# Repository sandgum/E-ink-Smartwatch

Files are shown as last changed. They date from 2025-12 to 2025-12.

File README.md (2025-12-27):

# Triangulate ES_01 E-ink Watch
---
An ultra-thin ESP32S3-based smartwatch (at just 5mm thick at its thickest point) which uses an E-ink display and two OLEDs to display information while consuming a small amount of power. The main E-ink panel is touch-enabled, with the two additional OLED panels above and below it displaying auxiliary information, such as notifications, background activities etc. 
The watch has built-in heart rate and spO2 sensing via an Analog Devices MAX30102, high-precision smart movement sensing via a Bosch BH260AP IMU and a Bosch BMP585 barometric pressure sensor.

render1
render10

*ACKNOWLEDGMENT: Most of the materials and the human hand model you see in the renders are not my own work, but is Royalty-free or CC0 licensed work legitimately downloaded from BlenderKit using their free plan*

---

To top it all off, the ES_01 is completely workout-friendly, with rubberised sides and no pesky side buttons that get pressed mid-pushup (Every physical input is at the top of the watch)!
The watch features a sleek design, with each component being laid out single file and in its own separate segment of the watch. These segments can all bend around the watch, preserving a uniform thickness all around, which also adds the benefit of being aesthetically pleasing.
The main microcontroller running the watch is an Espressif ESP32-S3 running with Bluetooth LE capabilities, which also allow for it to sync with a smartphone to relay notifications, workout, and weather data etc. through firmware based on ESP-IDF and host smartphone software for iPhone based on Swift (Coming soon, and Android support will come later!)

---
## PCB:

-  4 layers
-  Flex PCB
-  Single-sided component placement
-  0.2mm board thickness
-  Added 0.1mm FR4 stiffeners
-  All resistors and capacitors are 0402 size

*Schematics:*
E-ink watch sensors schematic
E-ink watch main schematic
E-ink watch drivers schematic
E-ink watch displays schematic

*PCB Layout and render:*
Screenshot 2025-12-14 at 1 22 46 pm
render4

---

## Enclosure:

- Main cases and top plates of easch segment 3D printed using an SLA/MSLA printer
- Main cases printed in Black resin from JLC3DP (can substitute with any rigid resin)
- Top plates printed in LEDO 6060 resin from JLC3DP (can substitute with any rigid resin)
- Bottom plates for OLED segments are CNC machined from 6061 Aluminium by JLCCNC (can substitute with any rigid material or also with SLA/MSLA printed resin)
- Bottom plate for main E-ink segment 3D printed using an SLM printer in 316L stainless steel (can substitute with other rigid metal with high thermal conductivity)

---

## Assembly instructions:

1. Use the solder stencil to squeegee solder paste onto main PCB
2. Place each component onto its respective pads on the main PCB
3. Use a hotplate or a reflow oven to reflow the solder paste underneath the components
4. Hand-solder a thin insulated wire (enamel insulated or rubber insulated) connecting the pads "BATT1_WIRE" together on the PCB
5. Create a solder bridge connecting the pads "GND_TO_GNDIO" and "GNDIO_TO_GND"
6. Create a solder bridge connecting the pads "GND_TO_GNDPWR" and "GNDPWR_TO_GND"
7. Assemble the two "end battery" segments by threading battery wires through them, placing the battery in and attaching the top plates to their respective main cases with superglue
8. Assemble the other battery segment and the haptic module segment in the same way, but thread the "end battery" wires through the dedicated channels in these segments, you should have two sets of two segments with four wires coming out of each set of segments
9. Take the main cases of the OLED modules and superglue the OLED displays into the top of each, making sure the flex cables poke through their dedicated holes
10. Do the same with the E-ink segment and the E-ink display
11. Attach each remaining top plate to its respective main case using superglue
12. Place and superglue the main Flex PCB into the bottom of the E-ink segment and the two OLED segments. The back of the PCB should face the displays
13. Thread the wires from the two sets of segments from step 8 through the holes in the side of the OLED modules and hand-solder the wires onto their respective pads
14. Plug in the flex cables from each display into thir respective FPC connectors on the main PCB
15. Superglue the bottom panels for the OLED segments onto their respective main cases
16. Apply thermal paste on the ESP32-S3 chip on the main PCB
17. Superglue threaded inserts in the two dedicated holes in the corners of the bottom panel for the E-ink segment
19. Superglue the bottom panel to the main case of the E-ink segment
20. Screw two screws into the holes in the top case of the E-ink segment until they mesh with the threaded inserts from the previous step
21. Take two more screws and cut off their entire threaded sections until just the heads remain. Superglue those heads in the holes in the other two corners of the top panel of the E-ink segment
22. Superglue the side TPU pieces to the sides of all the segments
23. Plug in a patch antenna into the exposed U.FL port on the back of the watch, guide the cable through its designated groove, and stick the patch antenna somewhere on the watch

---
## Bill of materials:

*Electronic Components: (Order quantities account for minimum order quantity of parts from the chosen retailer)*

| Manufacturer Part Number | Mfr. | Order Qty. | Unit Price(USD) | Ext.Price(USD) | Package | Description | Product Link |
|---|---|---|---|---|---|---|---|
| CC0402JRNPO9BN110 | YAGEO | 100 | 0.0012 | 0.12 | 0402 | 11pF ±5% 50V Ceramic Capacitor NP0 0402 | https://www.lcsc.com/product-detail/C527000.html |
| GRM155R61E475ME15D | muRata | 20 | 0.0377 | 0.75 | 0402 | 4.7uF ±20% 25V Ceramic Capacitor X5R 0402 | https://www.lcsc.com/product-detail/C2858031.html  |
| ESP32-S3 | ESPRESSIF | 1 | 2.7791 | 2.78 | QFN-56-EP(7x7) | 150Mbps 2.4GHz 2.412GHz~2.484GHz QFN-56-EP(7x7) RF Transceiver ICs RoHS | https://www.lcsc.com/product-detail/C2913192.html  |
| 2328702-6 | TE Connectivity | 5 | 0.1654 | 0.83 | SMD,P=0.5mm,Surface Mount,Right Angle  | FFC/FPC Connector 6 Position 0.5mm Pitch Double-Sided Contacts, Top and Bottom Entry Surface Mount, Right Angle -40℃~+85℃  | https://www.lcsc.com/product-detail/C3151647.html  |
| FFC2B28-24-G | Global Connector Technology | 1 | 0.5754 | 0.58 | SMD,P=0.5mm,Surface Mount,Right Angle  | FFC/FPC Connector 24 Position 0.5mm Pitch Double-Sided Contacts, Top and Bottom Entry Surface Mount, Right Angle -25℃~+85℃ | https://www.lcsc.com/product-detail/C3151659.html  |
| BHI260AP | Bosch | 1 | 8.7882 | 8.79 | LGA-44 | LGA-44 IMUs (Inertial Measurement Units) RoHS | https://www.lcsc.com/product-detail/C3288651.html  |
| SI1308EDL-T1-GE3 | VISHAY | 5 | 0.1324 | 0.66 | SOT-323 | N-Channel 30V 1.5A 0.4W Surface Mount SOT-323 | https://www.lcsc.com/product-detail/C469327.html |
| XC6206P302MR | HXY MOSFET | 50 | 0.0154 | 0.77 | SOT-23 | Linear Voltage Regulator IC Positive Fixed 1 Output 300mA SOT-23 | https://www.lcsc.com/product-detail/C5148691.html  |
| MBR0530 | Huixin | 20 | 0.0205 | 0.41 | SOD-123 | 5.5A 30V 500mV@500mA 500mA SOD-123 Single Diodes RoHS | https://www.lcsc.com/product-detail/C49435625.html |
| 0402WGF1004TCE | UNI-ROYAL | 100 | 0.0006 | 0.06 | 0402 | 1MΩ ±1% 62.5mW 0402 Thick Film Resistor | https://www.lcsc.com/product-detail/C26083.html |
| CL05A105KA5NQNC | Samsung Electro-Mechanics | 100 | 0.0030 | 0.30 | 0402 | 1uF ±10% 25V Ceramic Capacitor X5R 0402 | https://www.lcsc.com/product-detail/C52923.html |
| XL2EL89CPI-111YLC-40M | YXC Crystal Oscillators | 10 | 0.0578 | 0.58 | SMD3225-4P | Crystal 40MHz ±10ppm 15pF SMD3225-4P | https://www.lcsc.com/product-detail/C5444549.html  |
| TS-1088-AR02016 | XUNPU | 10 | 0.0421 | 0.42 | SMD,4x3mm | Tactile Switch SPST 160gf 2mm SMD (SMT) Tab 4mm x 3mm Surface Mount | https://www.lcsc.com/product-detail/C720477.html |
| BSS138 | R+O | 50 | 0.0170 | 0.85 | SOT-23 | N-Channel 50V 340mA 350mW Surface Mount SOT-23 | https://www.lcsc.com/product-detail/C7420339.html  |
| TCR2EF33,LM(CT | TOSHIBA | 5 | 0.0829 | 0.41 | TSOT-25 | Positive Fixed 3.3V TSOT-25 Voltage Regulators - Linear, Low Drop Out (LDO) Regulators RoHS | https://www.lcsc.com/product-detail/C843273.html |
| LQG15HS3N3S02D | muRata | 100 | 0.0076 | 0.76 | 0402 | 800mA 3.3nH 125mΩ 0402 Fixed Inductors RoHS | https://www.lcsc.com/product-detail/C86064.html |
| MRA4003T3G | onsemi | 10 | 0.0873 | 0.87 | SMA(DO-214AC) | Diode 300V 1A Surface Mount SMA(DO-214AC) | https://www.lcsc.com/product-detail/C94410.html |
| DRV2605LDGSR | TI | 1 | 1.2502 | 1.3 | VSSOP-10-0.5mm | 2V~5.2V I2C VSSOP-10-0.5mm Motor Drivers, Controllers RoHS | https://www.lcsc.com/product-detail/C527464.html |
| LQG15HS2N0S02D | muRata | 100 | 0.0081 | 0.81 | 0402 | 900mA 2nH 90mΩ 0402 Fixed Inductors RoHS | https://www.lcsc.com/product-detail/C18216.html |
| 0402WGF5603TCE | UNI-ROYAL | 100 | 0.0005 | 0.05 | 0402 | 560kΩ ±1% 62.5mW 0402 Thick Film Resistor | https://www.lcsc.com/product-detail/C132339.html |
| CL05B103KB5NNNC | Samsung Electro-Mechanics | 100 | 0.0014 | 0.14 | 0402 | 10nF ±10% 50V Ceramic Capacitor X7R 0402 | https://www.lcsc.com/product-detail/C15195.html |
| 0402B102K500NT | FH | 100 | 0.0011 | 0.11 | 0402 | 1nF ±10% 50V Ceramic Capacitor X7R 0402 | https://www.lcsc.com/product-detail/C1523.html |
| CL05B104KO5NNNC | Samsung Electro-Mechanics | 100 | 0.0012 | 0.12 | 0402 | 100nF ±10% 16V Ceramic Capacitor X7R 0402 | https://www.lcsc.com/product-detail/C1525.html |
| 0402CG1R0C500NT | FH | 100 | 0.0012 | 0.12 | 0402 | 1pF 50V Ceramic Capacitor C0G 0402 | https://www.lcsc.com/product-detail/C1550.html |
| CL05A106MQ5NUNC | Samsung Electro-Mechanics | 100 | 0.0044 | 0.44 | 0402 | 10uF ±20% 6.3V Ceramic Capacitor X5R 0402 | https://www.lcsc.com/product-detail/C15525.html |
| CL05B224KO5NNNC | Samsung Electro-Mechanics | 100 | 0.0044 | 0.44 | 0402 | 220nF ±10% 16V Ceramic Capacitor X7R 0402 | https://www.lcsc.com/product-detail/C16772.html |
| BMP585 | Bosch | 1 | 2.2083 | 2.21 | LGA-9(3.3x3.3) | 30Kpa~1.25bar LGA-9(3.3x3.3) Pressure Sensors, Transducers RoHS | https://www.lcsc.com/product-detail/C18184976.html |
| 0402WGF1001TCE | UNI-ROYAL | 100 | 0.0006 | 0.06 | 0402 | 1kΩ ±1% 62.5mW 0402 Thick Film Resistor | https://www.lcsc.com/product-detail/C11702.html |
| LD39200PU33R | ST | 1 | 1.2693 | 1.27 | DFN-6(3x3) | Positive Fixed 3.3V DFN-6(3x3) Voltage Regulators - Linear, Low Drop Out (LDO) Regulators RoHS | https://www.lcsc.com/product-detail/C222192.html |
| CL05A475MP5NRNC | Samsung Electro-Mechanics | 50 | 0.0048 | 0.24 | 0402 | 4.7uF ±20% 10V Ceramic Capacitor X5R 0402 | https://www.lcsc.com/product-detail/C23733.html |
| 0402WGF220JTCE | UNI-ROYAL | 100 | 0.0007 | 0.07 | 0402 | 22Ω ±1% 62.5mW 0402 Thick Film Resistor | https://www.lcsc.com/product-detail/C25092.html |
| 0402WGF220KTCE | UNI-ROYAL | 100 | 0.0009 | 0.09 | 0402 | 2.2Ω ±1% 62.5mW 0402 Thick Film Resistor | https://www.lcsc.com/product-detail/C25101.html |
| 0402WGF1002TCE | UNI-ROYAL | 100 | 0.0006 | 0.06 | 0402 | 10kΩ ±1% 62.5mW 0402 Thick Film Resistor | https://www.lcsc.com/product-detail/C25744.html |
| 0402WGF2201TCE | UNI-ROYAL | 100 | 0.0006 | 0.06 | 0402 | 2.2kΩ ±1% 62.5mW 0402 Thick Film Resistor | https://www.lcsc.com/product-detail/C25879.html |
| 0402WGF4701TCE | UNI-ROYAL | 100 | 0.0006 | 0.06 | 0402 | 4.7kΩ ±1% 62.5mW 0402 Thick Film Resistor | https://www.lcsc.com/product-detail/C25900.html |
| ANR4012T470M | APV | 10 | 0.0517 | 0.52 | SMD,4x4mm | 47uH Magnetic Shielded Inductor 500mA SMD,4x4mm Fixed Inductors RoHS | https://www.lcsc.com/product-detail/C7497063.html  |
| MAX30102EFD+T | MAXIM | 1 | 13.7281 | 13.73 | OESIP-14 | I2C OESIP-14 Specialized Sensors RoHS | https://www.lcsc.com/product-detail/C6454833.html  |
| LW06121 | WENDA | 100 | 0.07 | 7 | SMD,P=0.62mm,Surface Mount,Right Angle | 1.2H 14Pin 0.62mm Pitch OLED FPC/FFC Upper Contact Pull-Out Horizontal SMD Flat Connector | https://www.alibaba.com/product-detail/WENDA-LW06121-1-2H-14Pin-0_1601292173873.html |
| 1N4148 | onsemi | 50 | 0.0221 | 1.11 | DO-35 | Diode 100V 200mA Through Hole DO-35 | https://www.lcsc.com/product-detail/C258182.html |
| GDEY0154D67-T03 | Goodisplay | 1 | 11.32 | 11.32 | - | 1.54Inch Touch E-Paper 200x200 E-Ink Display | https://www.aliexpress.com/item/1005005200574055.html |
| SSD1306 | - | 2 | 0.72 | 1.44 | - | 0.91 Inch I2C OLED Module | https://www.aliexpress.com/item/1005004415958608.html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 |
| 401225 | - | 3 | 2.66 | 7.98 | - | 3.7V 100mAh Lithium Polymer Lipo Rechargeable Battery | https://www.aliexpress.com/item/1005006129236699.html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 |
| 0619AAC | - | 1 | 3.06 | 3.06 | - | Brushless X-axis 1.2V 100mA Max Precision Vibration Motor | https://www.aliexpress.com/item/1005006421331249.html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 |
| TS-A002 | - | 20 | 0.069 | 1.38 | - | Momentary Tact Switch SMD | https://www.aliexpress.com/item/1005008702742151.html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 |
| - | - | 50 | 0.0264 | 1.32 | - | M1.4 Torx countersunk machine screw 4mm length | https://www.aliexpress.com/item/33006942612.html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 |
| - | - | 50 | 0.0244 | 1.22 | - | M1.4 Brass threaded inserts 1.5mm length | https://www.aliexpress.com/item/1005007653131713.html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 |

Total: $85.43 USD

*Manufactured Components*

| Description | Manufacturer | Material | Price (USD) |
|---|---|---|---|
| 3D Printed Enclosure Main Cases | JLC3DP | Black Resin | 7.05 |
| 3D Printed Enclosure Top Plates | JLC3DP | LEDO 6060 Resin | 2.11 |
| CNC Machined OLED Segment Bottom Plates | JLCCNC | Aluminium 6061 | 17.46 |
| SLM 3D Printed Main Segment Bottom Plate | JLC3DP | 316L Stainless Steel | 8.39 |
| Main 4-layer Flex PCB | JLCPCB | Yellow 0.2mm Polyimide with 0.1mm FR4 Stiffener | 94.00 |
| SMD Stencil for Main Flex PCB | JLCPCB | Steel | 7.47 |

Total: $136.48 USD

---
## Grand Total (Excl. Shipping): $221.91 USD
---

render2
render3
render7
render9
render6
render5

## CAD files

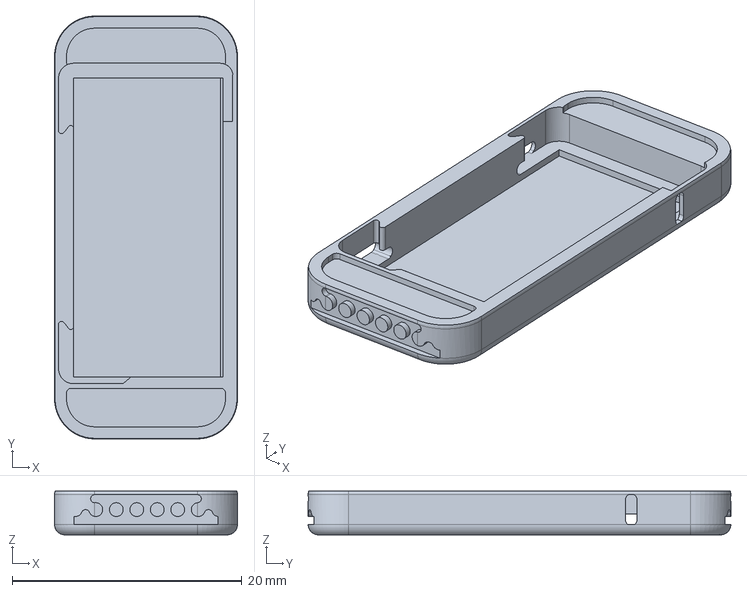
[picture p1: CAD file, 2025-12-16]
CAD/Battery Segment/main case (battery).step
15.9 x 36.8 x 3.81 mm

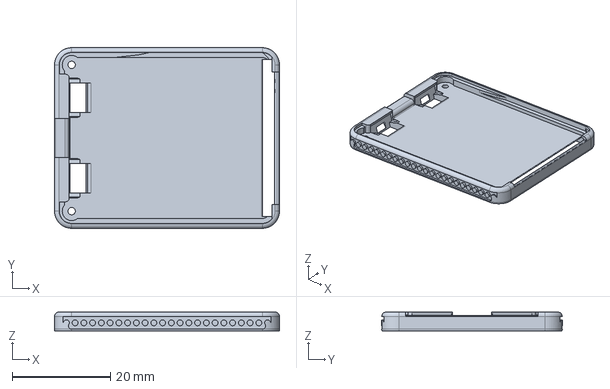
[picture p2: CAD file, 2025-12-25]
CAD/E-Ink Segment/main case (E-ink).step
45.8 x 36.8 x 3.85 mm

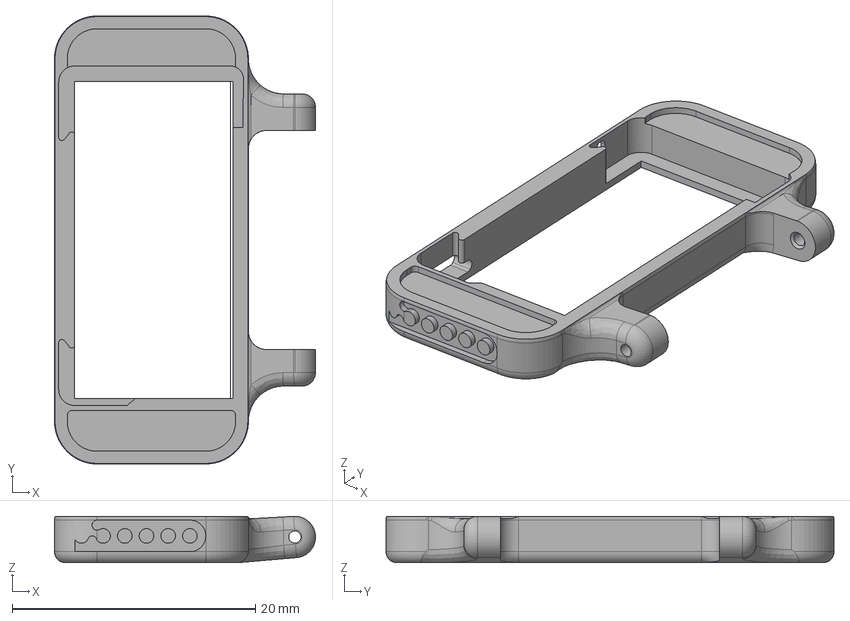
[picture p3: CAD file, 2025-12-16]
CAD/End Battery Segment 2/main case (end battery 2).step
21.4 x 36.8 x 3.81 mm

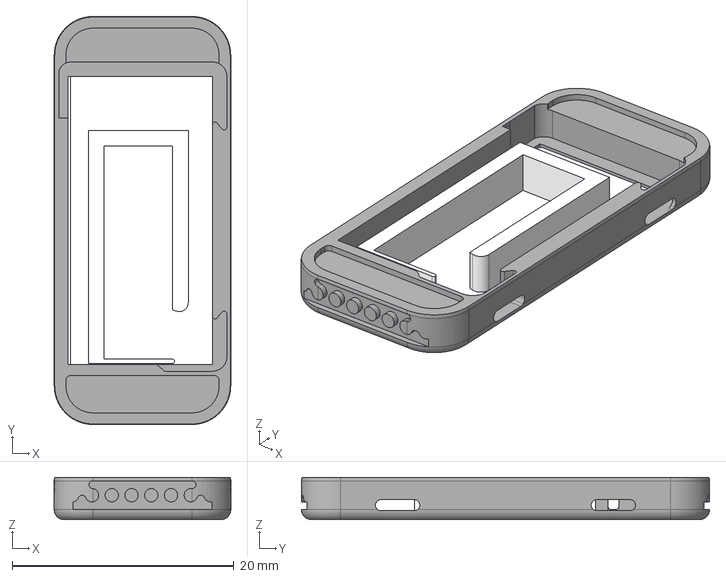
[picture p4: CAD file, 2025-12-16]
CAD/Haptic Segment/main case (haptic).step
15.9 x 36.8 x 3.81 mm

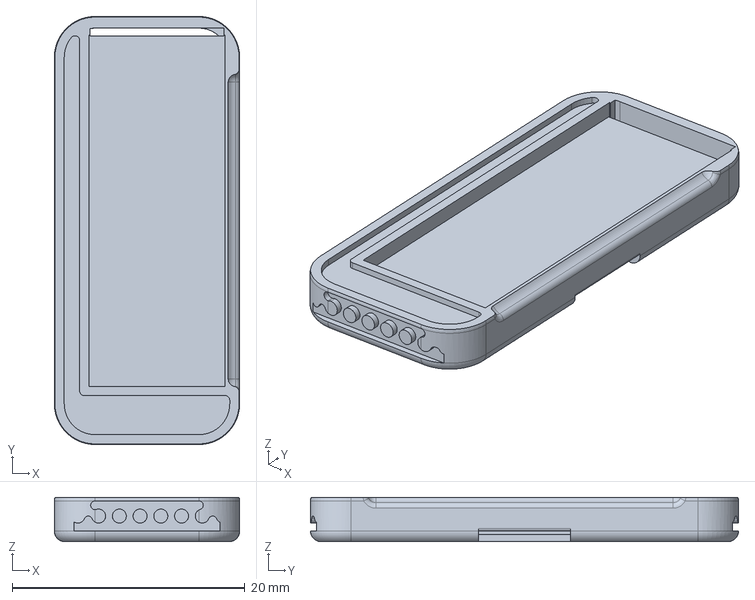
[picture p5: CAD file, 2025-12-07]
CAD/OLED Segment 2/main case (OLED 2).step
15.9 x 36.8 x 3.81 mm

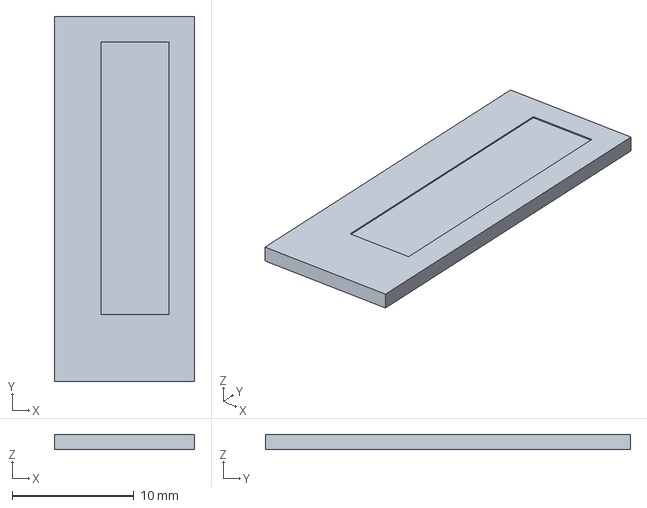
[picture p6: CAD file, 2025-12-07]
CAD/Components/oled display (2).step
11.5 x 30.0 x 1.20 mm

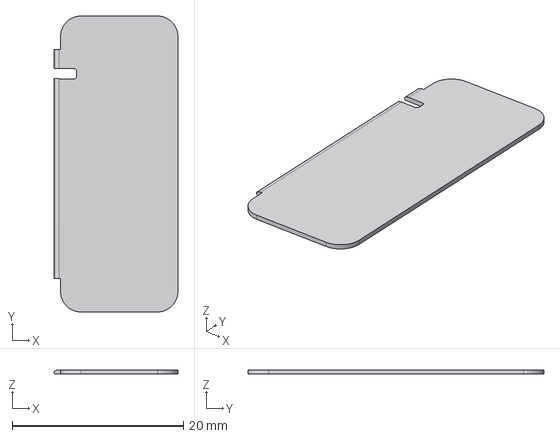
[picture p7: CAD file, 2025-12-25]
CAD/OLED Segment/bottom plate (OLED).step
14.5 x 34.6 x 0.5 mm

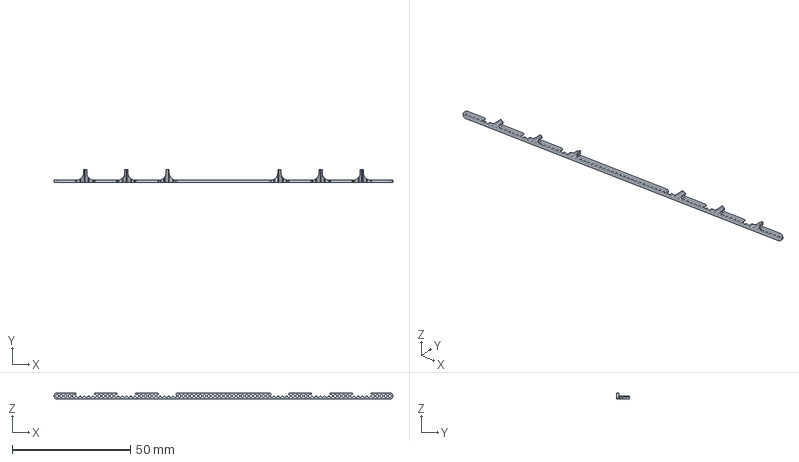
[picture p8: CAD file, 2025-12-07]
CAD/Side TPU Pieces/Side TPU.step
143.4 x 5.40 x 2.60 mm

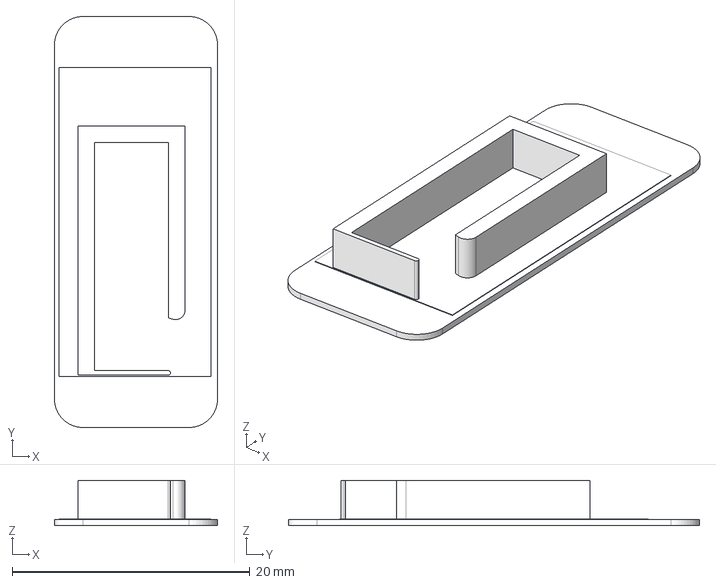
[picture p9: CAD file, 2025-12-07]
E-ink watch Enclosure STEP files/Haptic Segment/bottom plate (haptic).step
13.7 x 34.6 x 3.81 mm

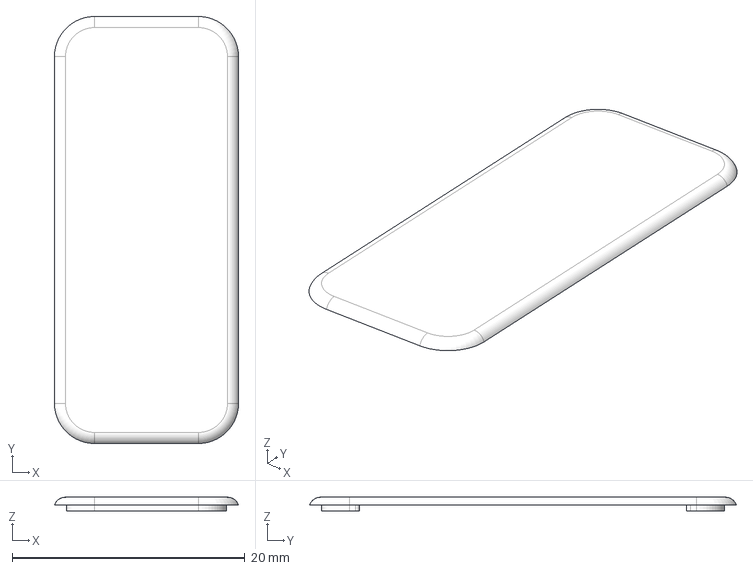
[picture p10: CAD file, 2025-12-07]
CAD/Battery Segment/top plate (battery).step
15.8 x 36.7 x 1.17 mm

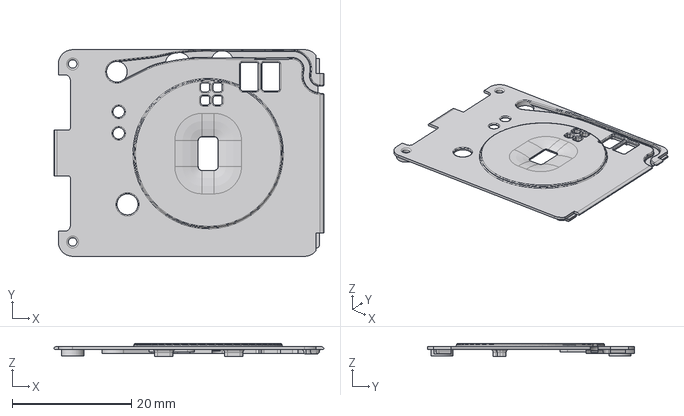
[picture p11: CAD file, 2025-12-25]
CAD/E-Ink Segment/bottom plate (E-ink).step
45.2 x 34.6 x 2.20 mm

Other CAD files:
CAD/End Battery Segment/main case (end battery).step
CAD/OLED Segment/main case (OLED).step
E-ink watch Enclosure STEP files/Battery Segment/bottom plate (battery).step
E-ink watch Enclosure STEP files/End Battery Segment 2/bottom plate (end battery 2).step
E-ink watch Enclosure STEP files/End Battery Segment/bottom plate (end battery).step
CAD/End Battery Segment 2/top plate (end battery 2).step
CAD/End Battery Segment/top plate (end battery).step
CAD/Components/100mah battery (2).step
CAD/Components/100mah battery (3).step
CAD/Components/100mah battery (4).step
CAD/Components/Button (1).step
CAD/Components/Button.step
CAD/Components/M1.4 4mm torx screw (1).step
CAD/Components/M1.4 4mm torx screw fake.step
CAD/Components/M1.4 4mm torx screw fake_2.step
CAD/Components/M1.4 4mm torx screw.step
CAD/Components/e ink display.step
CAD/Components/haptic motor.step
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

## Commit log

2025-12-11 Updated KiCAD files to include finished schematic
    [E-ink watch.kicad_pcb, E-ink watch.kicad_sch, OLED_circuits.kicad_sch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]
2025-12-16 Add updated enclosure STEP files
    Bottom plates and main cases of the end battery segments, the main battery segment and the haptic segment have been merged to make sure all parts comply with JLC3DP minimum printing restrictions
    [100mah battery (2).step, 100mah battery (3).step, 100mah battery (4).step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]
2025-12-16 Added PCB schematics in the form of PDFs
2025-12-23 Update README with PCB BoM and other PCB stuff
2025-12-25 Change Folders Layout
    [100mah battery (2).step, 100mah battery (3).step, 100mah battery (4).step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]
2025-12-25 Add final CAD folder (as per Blueprint guidelines)
    [100mah battery (2).step, 100mah battery (3).step, 100mah battery (4).step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]
2025-12-25 Update README.md with acknowledgment of Blender Render materials
2025-12-25 Update README.md with assembly instructions
2025-12-25 Add both BOM Files as CSV
    [Electronics_BOM.csv, Manufactured_Parts_BOM.csv]
2025-12-27 Update BOM in README.md with screws and inserts, and update assembly instructions
